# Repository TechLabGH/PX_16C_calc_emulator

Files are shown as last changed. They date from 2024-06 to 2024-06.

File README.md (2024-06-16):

# PX_16C_calc_emulator
all credits go to [paxer.net/voyager/](https://paxer.net/voyager/)

This is great project and useful tool for programmers. I personally prefer that over any software emulator.

Respository is for anybody who would like to COPY of one orderred from developer. This is only partially "open" project. Developer provides schematic and firmware. There is no source code available. Also, Atmega, you are ordering is pre-loaded with flash required to work.

I only re-drafted PCB using SMD componnents (no buzzer due to smaler size). You still would order original kit (let author be paid for his effort) to download flash dump for your copies.

## [Schematic](https://github.com/TechLabGH/PX_16C_calc_emulator/blob/main/HP%2016C%20Pocket.pdf)

Parts:
* [ATMEGA328-AUR](https://www.mouser.com/ProductDetail/556-ATMEGA328-AUR)
* [Crystal](https://www.mouser.com/ProductDetail/710-830003000)
* [Battery Holder](https://www.mouser.com/ProductDetail/12BH002-GR)
* 6x6 Tactile Switches - select high to match your project
* 10ohm / 10Kohm / 2 x 0.1uF - 0603 size
* [Reset button](https://www.mouser.com/ProductDetail/Wurth-Elektronik/431181015816?qs=wr8lucFkNMWQBPdjQ%252B9NsA%3D%3D) - not really needed if your programmer has reset signal.
* [Screen](https://www.aliexpress.us/item/2255800684095628.html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) - any 2" 192X64 Graphic Matrix LCD Module Display Screen 3.3V - UC1609C would fit. Make sure to buy 3.3V version. Window in top board is made for display's version without metal cover.

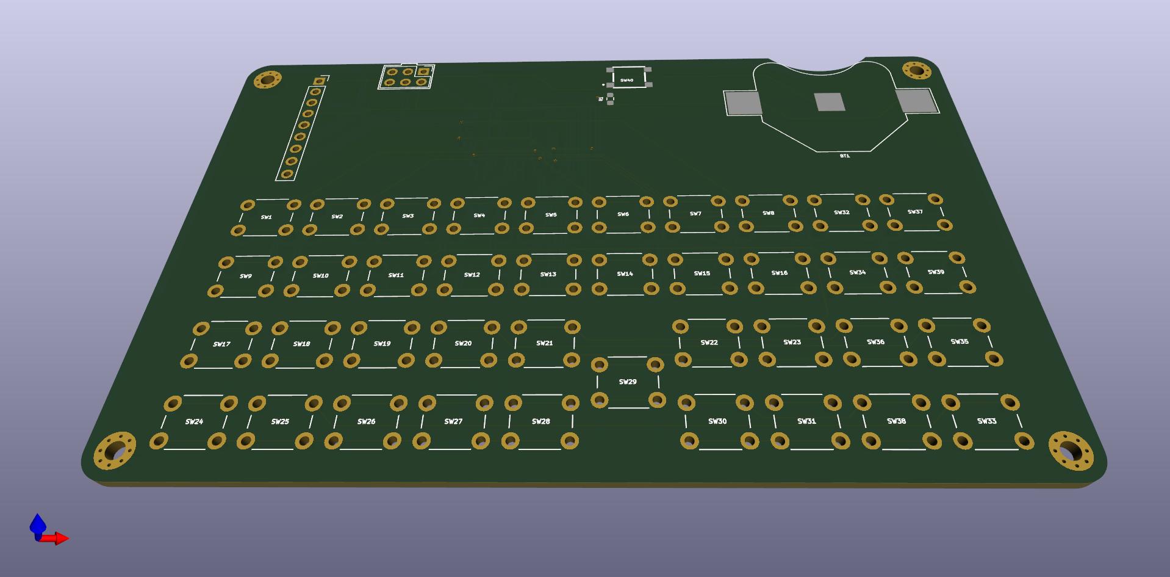
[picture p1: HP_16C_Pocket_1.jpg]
Main-1


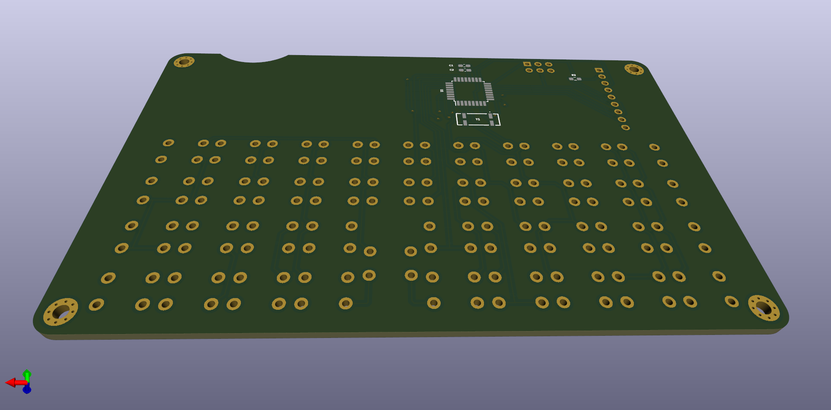
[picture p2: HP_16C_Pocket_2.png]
Main-2


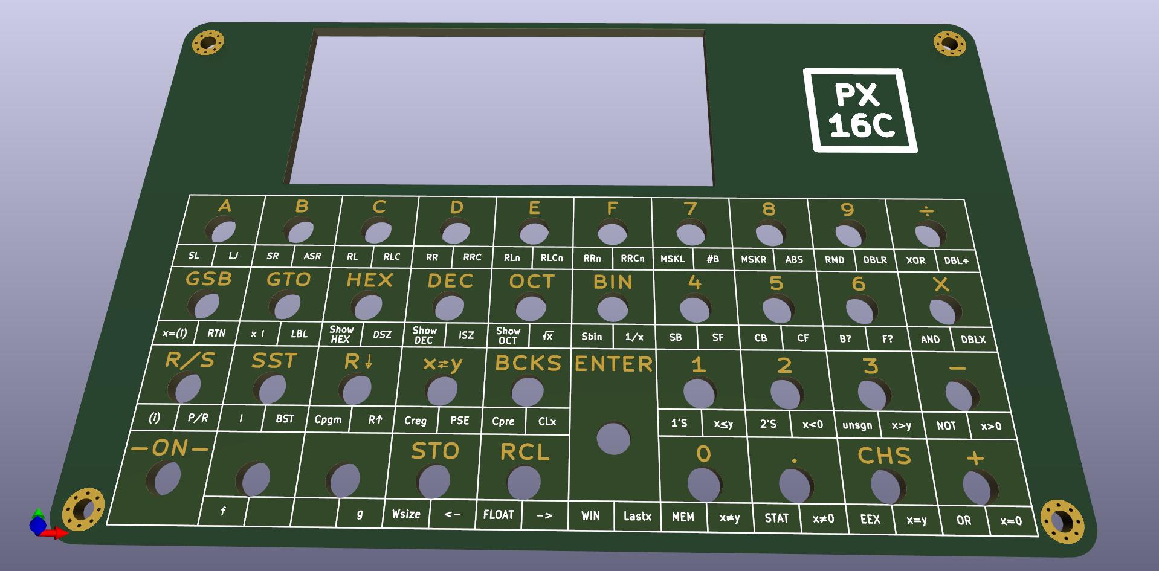
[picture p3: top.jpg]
Top


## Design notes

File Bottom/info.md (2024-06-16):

Bottom PCB is simply blank board cut to size with holes

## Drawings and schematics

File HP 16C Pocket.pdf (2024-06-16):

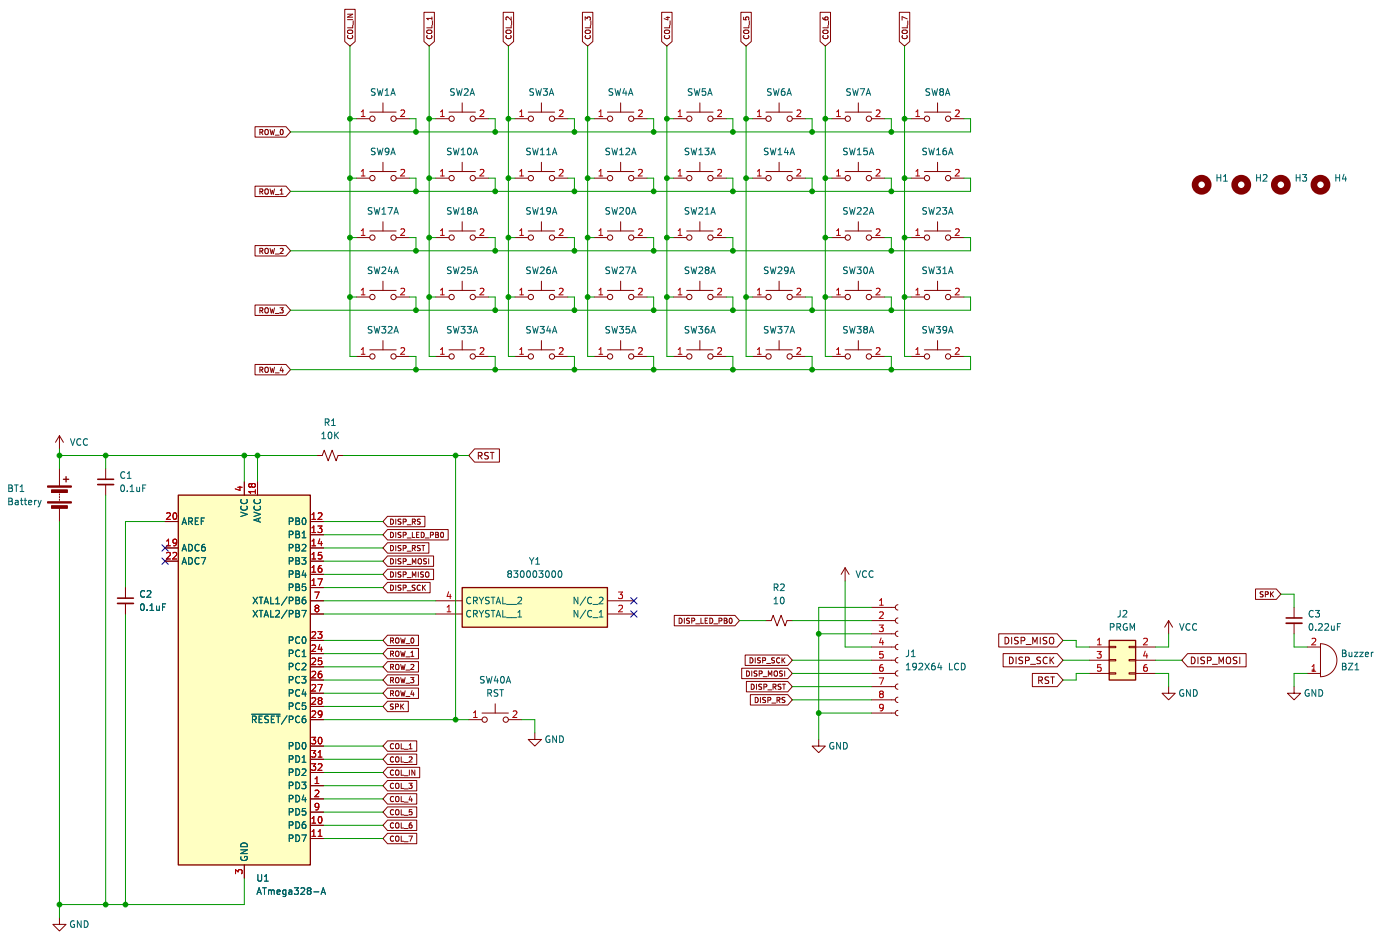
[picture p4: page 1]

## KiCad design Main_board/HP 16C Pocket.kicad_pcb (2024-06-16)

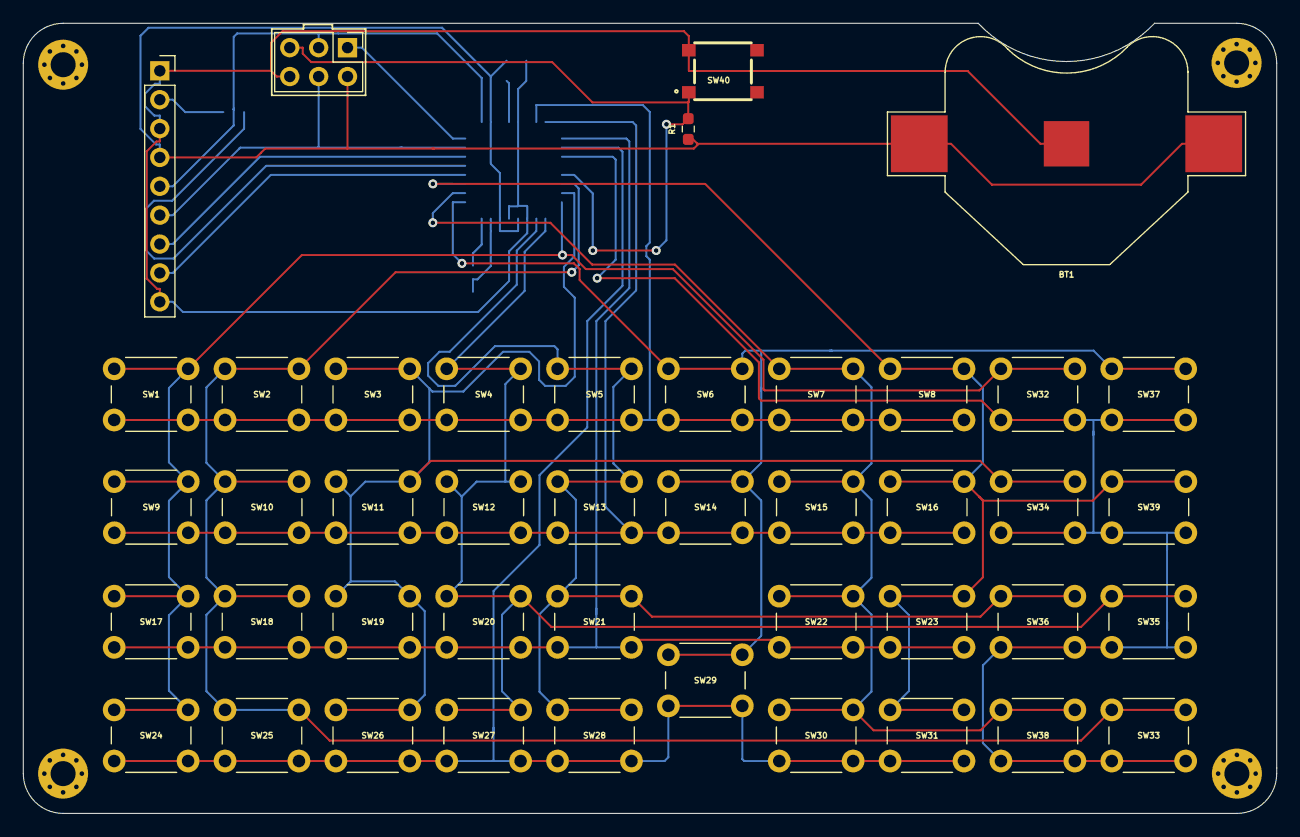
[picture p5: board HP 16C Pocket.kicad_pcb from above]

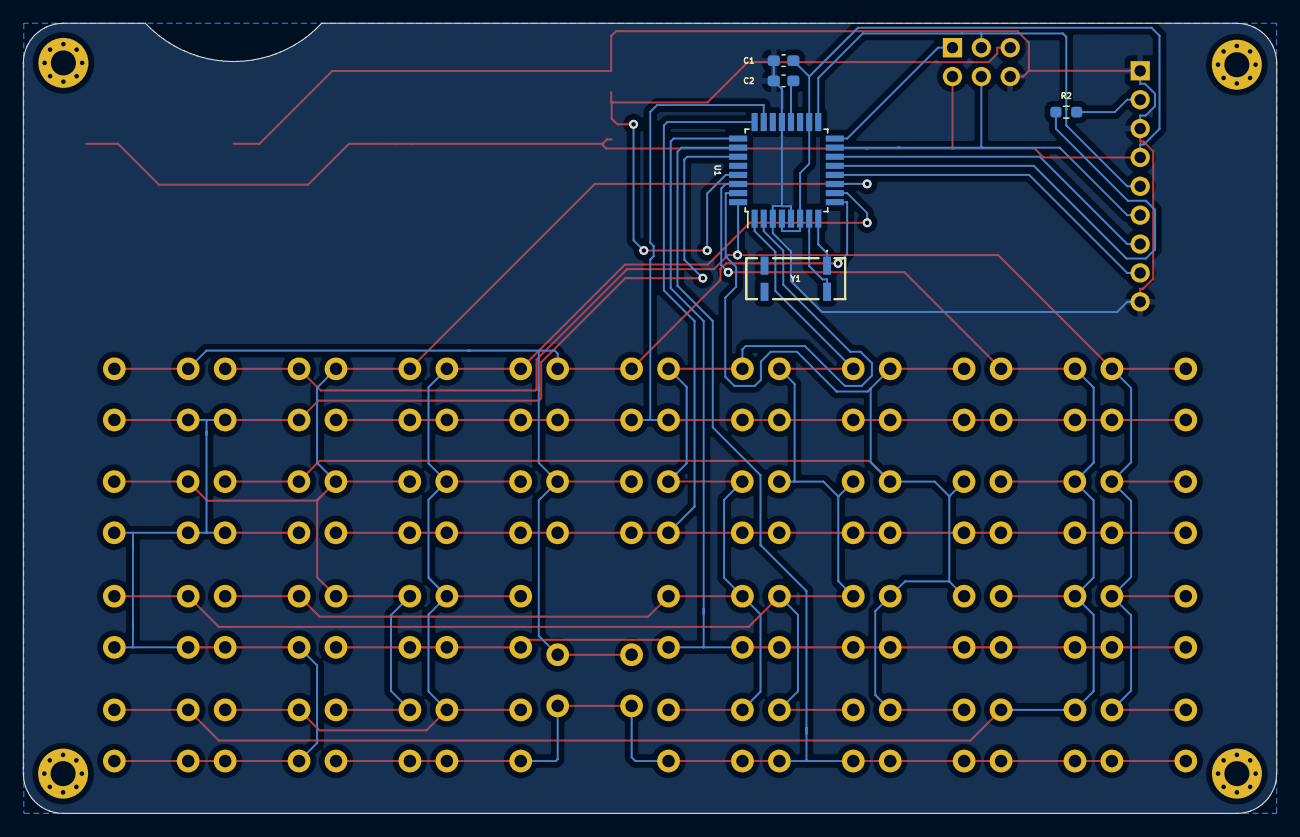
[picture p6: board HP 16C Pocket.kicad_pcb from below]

Board: 2 copper layers, 110.2 x 69.5 mm, 53 parts (5 on the bottom side), 26 nets.

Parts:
BT1: Battery; BatteryHolder_Multicomp_BC-2001_1x2032
C1, C2: 0.1uF; C_0603_1608Metric_Pad1.08x0.95mm_HandSolder
H1, H2, H3, H4: MountingHole; MountingHole_2.2mm_M2_Pad_Via
J1: 192X64 LCD; PinSocket_1x09_P2.54mm_Vertical
J2: PRGM; PinHeader_2x03_P2.54mm_Vertical
R1: 10K; R_0603_1608Metric_Pad0.98x0.95mm_HandSolder
R2: 10; R_0603_1608Metric_Pad0.98x0.95mm_HandSolder
SW1, SW2, SW3, SW4, SW5, SW6, SW7, SW8, SW9, SW10, SW11, SW12, SW13, SW14, SW15, SW16, SW17, SW18, SW19, SW20, SW21, SW22, SW23, SW24, SW25, SW26, SW27, SW28, SW29, SW30, SW31, SW32, SW33, SW34, SW35, SW36, SW37, SW38, SW39: SW_Push_Dual_x2; SW_PUSH_6mm
SW40: RST; 431181015816
U1: ATmega328-A; TQFP-32_7x7mm_P0.8mm
Y1: 830003000

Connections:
COL_1: SW2.1 (C), SW10.1 (C), SW18.1 (C), SW25.1 (C), SW33.1 (C), U1.30 (PD0)
COL_2: SW3.1 (C), SW11.1 (C), SW19.1 (C), SW26.1 (C), SW34.1 (C), U1.31 (PD1)
COL_3: SW4.1 (C), SW12.1 (C), SW20.1 (C), SW27.1 (C), SW35.1 (C), U1.1 (PD3)
COL_4: SW5.1 (C), SW13.1 (C), SW21.1 (C), SW28.1 (C), SW36.1 (C), U1.2 (PD4)
COL_5: SW6.1 (C), SW14.1 (C), SW29.1 (C), SW37.1 (C), U1.9 (PD5)
COL_6: SW7.1 (C), SW15.1 (C), SW22.1 (C), SW30.1 (C), SW38.1 (C), U1.10 (PD6)
COL_7: SW8.1 (C), SW16.1 (C), SW23.1 (C), SW31.1 (C), SW39.1 (C), U1.11 (PD7)
COL_IN: SW1.1 (C), SW9.1 (C), SW17.1 (C), SW24.1 (C), SW32.1 (C), U1.32 (PD2)
DISP_LED_PB0: R2.1, U1.13 (PB1)
DISP_MISO: J2.1, U1.16 (PB4)
DISP_MOSI: J1.6, J2.4, U1.15 (PB3)
DISP_RS: J1.8, U1.12 (PB0)
DISP_RST: J1.7, U1.14 (PB2)
DISP_SCK: J1.5, J2.3, U1.17 (PB5)
GND: BT1.2 (-), C1.2, C2.2, J1.1, J1.3, J1.9, J2.6, SW40.2 (D), U1.3 (GND), U1.5 (GND), U1.21 (GND)
unnamed: J1.2, R2.2
unnamed: C2.1, U1.20 (AREF)
unnamed: U1.7 (XTAL1/PB6), Y1.4 (CRYSTAL__2)
unnamed: U1.8 (XTAL2/PB7), Y1.1 (CRYSTAL__1)
ROW_0: SW1.2 (D), SW2.2 (D), SW3.2 (D), SW4.2 (D), SW5.2 (D), SW6.2 (D), SW7.2 (D), SW8.2 (D), U1.23 (PC0)
ROW_1: SW9.2 (D), SW10.2 (D), SW11.2 (D), SW12.2 (D), SW13.2 (D), SW14.2 (D), SW15.2 (D), SW16.2 (D), U1.24 (PC1)
ROW_2: SW17.2 (D), SW18.2 (D), SW19.2 (D), SW20.2 (D), SW21.2 (D), SW22.2 (D), SW23.2 (D), U1.25 (PC2)
ROW_3: SW24.2 (D), SW25.2 (D), SW26.2 (D), SW27.2 (D), SW28.2 (D), SW29.2 (D), SW30.2 (D), SW31.2 (D), U1.26 (PC3)
ROW_4: SW32.2 (D), SW33.2 (D), SW34.2 (D), SW35.2 (D), SW36.2 (D), SW37.2 (D), SW38.2 (D), SW39.2 (D), U1.27 (PC4)
RST: J2.5, R1.2, SW40.1 (C), U1.29 (~RESET/PC6)
VCC: BT1.1 (+), C1.1, J1.4, J2.2, R1.1, U1.4 (VCC), U1.6 (VCC), U1.18 (AVCC)
